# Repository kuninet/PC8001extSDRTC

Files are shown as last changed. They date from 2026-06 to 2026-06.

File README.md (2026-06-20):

# PC8001extSDRTC

PC-8001 の外部CPUバスに直結する **PICマイコン式 SDカード + RTC ドライブ** の設計資料リポジトリです。

SDアクセスを、PC-8001 のCPU外部バスに接続した **PIC18F47Q43** に肩代わりさせ、SDカードを
**Z80 の I/O デバイス**として見せます。将来は I2C RTC(DS3231等)も同じデバイスに同居させます。

ソフト側(SD-DOS)から見ると、SDアクセス下回りのドライバ(`MMC.asm`)を I/O ポート版
(`MMC_PIC.asm`)に差し替えるだけで使えます。上位のファイルシステム層は無変更です。

- ソフト本体(SD-DOS): https://github.com/kuninet/SD-DOS
- I/O プロトコル仕様(最重要): [docs/protocol.md](docs/protocol.md)
- 兄弟プロジェクト(同じ外部バス直結の流儀): [PC8001ext232C](https://github.com/kuninet/PC8001ext232C)

> ⚠️ 本リポジトリは **設計段階**です。回路・基板・PICファームはこれから物理試作します。
> まずは I/O プロトコルと、SD-DOS 側のドライバ差し替え構成を固める段階です。

## なぜ作るのか(背景)

SD-DOS の SDアクセスは 8255 PPI を使った **ビットバンギング SPI** です。これは1セクタ
(512バイト)の読み出しに実機(Z80 実効約1.84MHz)で **約0.1秒**かかり、密に音符が並ぶ
VGM再生などでは「もたつき」が出ます(Issue #68 の割り込み駆動プレイヤ検証で、ソフトの
工夫では消せないと結論)。

そこで下回りを **ハードSPI(MHz級)を持つPIC**に置き換えると、1セクタ読みが **~0.5ms** 前後、
**約200倍**高速化します。同期読みのままでももたつかなくなり、割り込み背景読みのような
小細工も不要になります。

## 設計方針(A案: 生512Bブロックデバイス)

PIC は **「512バイト単位のランダムアクセス I/O デバイス」**に徹します。

- FAT 等のファイルシステムは **Z80(SD-DOS)側**のまま。PIC は生ブロックの R/W だけを担う。
- CP/M など他のソフトからも汎用的に使える(ファイルシステム非依存)。
- PIC は周辺を全エミュレートするのではなく、**I/O 周辺デバイスに徹する**。
  クロック・主ROM・主RAM は PC-8001 が供給する(EMUZ80 とは役割が逆)。

## アーキテクチャ

```mermaid
flowchart LR
    subgraph PC["PC-8001 外部CPUバス (5V)"]
        BUS["A0-A7 / D0-D7<br/>/IORQ /RD /WR /RESET"]
        WAIT["/WAIT (PICが駆動)"]
    end

    PIC["PIC18F47Q43<br/>I/Oポートデコード (D0H-D6H)<br/>512B セクタバッファ<br/>コマンド/データ/ステータス"]
    SD["microSD"]
    RTC["RTC DS3231 (将来)"]

    BUS <-->|"A0-A7 / D0-D7 / 制御"| PIC
    PIC -->|"/WAIT ハンドシェイク"| WAIT
    PIC <-->|SPI| SD
    PIC <-.->|I2C| RTC
```

I/O ポートは PC-8001 未割り当ての拡張領域 **D0H-D6H** に割り当てます。
詳細は [docs/protocol.md](docs/protocol.md) を参照してください(SD-DOS と共有する契約)。

| ポート | R/W | 役割 |
|---|---|---|
| D0H | W | コマンド(0=READ, 1=WRITE, 2=STATUS, 3=INIT、将来RTC) |
| D1H-D4H | W | セクタアドレス 32bit(LSB→MSB) |
| D5H | R/W | データFIFO(512B セクタバッファ ストリーム入出力) |
| D6H | R | ステータス(bit0=READY, bit1=BUSY, bit7=ERROR) |

### タイミングの見積り

実効1.84MHz → 1 I/O サイクル ≒ 2.2μs。PIC を64MHzで回すと **約35命令ぶん**の猶予があり、
EMUZ80 の 1350ns/21命令より約5倍楽です。単純なレジスタ応答は /WAIT 無しでも届く見込みですが、
**/WAIT で安全マージンを取る**設計にします。遅いSD読み中(~0.5ms)はZ80を /WAIT で固めず、
ステータスを polling して待つ方式とし、N-BASIC の割り込みを止めません。

## PIC を PIC18F47Q43 にする理由

| 型番 | RAM | Flash | MaxMHz | CLC | 備考 |
|---|---|---|---|---|---|
| **PIC18F47Q43(採用)** | 8KB | 128KB | 64 | あり | 512Bバッファ後も余裕、EMUZ80 実績、SPI×2/I2C |
| PIC18F46K22 | 4KB | 64KB | 64 | なし | バッファは足りるが余裕減、デコード外付け要かも |
| PIC18F4550 以下 | ≤2KB | ≤32KB | ≤48 | なし | 512Bバッファでほぼ埋まる(非推奨) |

RAM 8KB は 512B セクタバッファ + 将来のダブルバッファ / FATキャッシュ余地に効きます。
CLC(Configurable Logic Cell)で I/O ポートデコードをハード化でき、応答に余裕が出ます。

## SD-DOS 側のビルド分け

SD-DOS は **ビットバンギング(既定)** と **PICSD** を同一ソースから作り分けます。

- `src/LABELS.asm` の `USE_PICSD EQU FALSE`(既定)を `TRUE` にすると PIC版になる。
- `src/MMC.asm`(8255ビットバンギング)/ `src/MMC_PIC.asm`(D0H-D6H I/O)を条件INCLUDEで切替。
- ビルド: 既定 `make` がビットバンギング、`make picsd` が PIC版(`build/MAIN-PICSD.cmt`)。

詳細は SD-DOS リポジトリを参照してください。

## ロードマップ

1. **/WAIT 実機検証(最優先)**: 最小PICで「D0H 読み書きエコー + /WAIT アサート/解除」だけ作り、
   PC-8001 外部バスが /WAIT を尊重するか実機確認する。
2. **PIC SDファーム**: SPI初期化 + CMD17/CMD24 でセクタ R/W、512Bバッファ、ステータス。
   ロジックアナライザで I/O プロトコルを確認する。
3. **SD-DOS `MMC_PIC.asm` 結合**: Mac側の回帰テストをフック差し替えで通し、実機で R/W。
4. **実機体感**: VGMPLAY で「もたつき消滅」を確認(本丸)。
5. **RTC フェーズ**: D0H コマンドに時計 R/W を追加、I2C DS3231 等。

## ディレクトリ構成

```
PC8001extSDRTC/
├── README.md          このファイル(設計概要)
├── Makefile           PC-8001側テスト(WAITTEST)ビルド / firmware構文チェック
├── tools/             外部ツール(tools80.jar を置く。本体は再配布しないため非コミット)
├── docs/
│   └── protocol.md    D0H-D6H I/O 仕様(SD-DOS と共有する契約。最重要)
├── hardware/
│   └── design.md      回路設計仕様・結線表・ピンアサイン・BOM
├── firmware/          PIC18F47Q43 ファーム(MPLAB X / XC8)。今は構成と関数スタブ
│   └── waittest/      /WAIT 検証用スタブ
└── test/              /WAIT ハンドシェイク検証(PC-8001側 WAITTEST.asm + 手順)
```

## ビルド

PC-8001 アセンブラ tools80.jar を `tools/` に置きます(入手方法は [tools/README.md](tools/README.md)。
ツール本体は再配布しないためリポジトリには含めません)。SD-DOS など他リポジトリには依存しません。

```sh
make            # build/WAITTEST.cmt(PC-8001側 /WAIT 検証)を生成
make fw-check   # firmware の C スタブをホストで構文チェック
```

別の場所の jar を使う場合は `make TOOLS80=/path/to/tools80.jar`。PIC ファーム本体の実機
ビルドは MPLAB X + XC8 で行います。

## 将来検討: PC-80S31(FD)互換モード

PIC+SD を PC-80S31(NEC純正フロッピーユニット)のホストインターフェースに似せれば、
無改造の N-BASIC DISK BASIC / NEC CP/M が動く可能性があります(膨大な .D88 資産が使える)。
ただし PC-80S31 は Z80+μPD765 を積んだ知的サブシステムで、互換ファームは A案の単純な
ブロックデバイスより遥かに重く、フロッピー意味論に制約されます。**当面は A案を主とし、
PIC がバス上にいる利点を活かして将来「モード」として追加し得る**設計に留めます。

## ライセンス

MIT License. [LICENSE](LICENSE) を参照してください。

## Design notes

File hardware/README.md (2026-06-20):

# hardware — 回路図・基板(設計メモ)

PC-8001 外部CPUバスに直結する PIC18F47Q43 ボードのハードウェア設計です。
回路図・基板は KiCAD で起こす予定です(本ディレクトリに追加)。

- **[design.md](design.md) … 回路設計仕様・結線表(フェーズA)。基本方針・ブロック図・
  ピンアサイン表・ネット単位の結線表・BOM。KiCAD はこの結線表をもとに引く。**

## 接続するバス信号(PC-8001 拡張バス → PIC)

- アドレス: `A0`-`A7`(I/O ポートデコード用。`D0H`-`D6H` を識別)
- データ: `D0`-`D7`(双方向。PIC が `IN` 時にドライブ)
- 制御: `/IORQ`, `/RD`, `/WR`, `/RESET`
- `/WAIT`: **PIC が駆動**(オープンコレクタ/オープンドレインで Wired-OR)

## PIC 側ペリフェラル

- microSD: ハードSPI(MSSP1)。CS/SCK/MOSI/MISO。
- (将来)RTC: I2C(MSSP2)。DS3231 等。SDA/SCL に 4.7kΩ プルアップ。
- I/O デコード: CLC(Configurable Logic Cell)で `A7..A0 == D0H..D6H` かつ `/IORQ` を
  ハード判定し、応答レイテンシを詰める。

## 検討事項(要実機検証)

- **/WAIT を PC-8001 拡張バスが尊重するか**(最優先)。尊重しない場合の回避策はソフト側で。
- データバス バッファ(74xx245 等)の向き制御を `/RD`・デコード出力で行うか、PIC直結か。
- 5V(PC-8001)と 3.3V(SD/PIC)のレベル変換。PIC18F47Q43 は 5V 動作可だが、SD は 3.3V。
- 拡張バスのバスタイミング(セットアップ/ホールド)の実測(ロジックアナライザ)。

## ポートマップ

I/O ポート割り当て(`D0H`-`D6H`)は [../docs/protocol.md](../docs/protocol.md) を参照。

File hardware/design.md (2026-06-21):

# PICSD 回路設計仕様・結線表(フェーズA)

PIC18F47Q43 を PC-8001 外部CPUバスに直結し、SDカードを D0H-D6H の I/O デバイスとして
見せるボードの設計仕様です。KiCad 入力前の「何をどう繋ぐか」を確定します。

> ✅ ピン番号・PPS 割り当て・I2C 専用 pin はデータシート(DS40002147E, Rev.E)で照合済み。
> 実機で詰める項目(/WAIT タイミング、I2C 標準レベル動作、バスバッファ要否)は §6 に分けています。

## 1. 基本方針

- **PIC は 5V 単一電源で動作させる**(PIC18F47Q43 は 5V 動作可)。
  - 理由: PC-8001 拡張バスは 5V TTL。PIC を 5V で回せば**バス側のレベル変換が一切不要**になり、
    部品点数が激減する(EMUZ80 と同じ思想)。
  - 3.3V が要るのは microSD だけ。これは **オンボードに 3.3V レギュレータ + レベル変換を持つ
    microSD モジュール**(既存 SD-DOS で使う [sdd](https://github.com/chiqlappe/sdd) 相当)を使い、
    SPI 信号は 5V ロジックのままモジュールに渡してモジュール内で整える。→ ボード上に個別の
    レベル変換ICを置かない。
  - RTC(将来)は DS3231 モジュール(5V トレラント、オンボード I2C プルアップ)を想定し、
    I2C も 5V のまま接続。
- **クロックは内部 64MHz HFINTOSC**。水晶不要(→ OSC ピンを GPIO に回せる)。
- I/O ポートデコード(`A7..A0 == D0H..D6H` かつ `/IORQ`)は **CLC でハード化**して応答を詰める。
  SPI/CLC のピンは PPS で自由に割り当て可能。

### レベル変換まとめ

| 境界 | 信号 | 方式 |
|---|---|---|
| PC-8001 ↔ PIC | A0-A7, D0-D7, /IORQ, /RD, /WR, /RESET, /WAIT | **変換なし**(両側 5V) |
| PIC ↔ microSD | SPI(SCK/MOSI/MISO/CS) | **microSDモジュールのオンボード変換**に委ねる |
| PIC ↔ RTC(将来) | I2C(SCL/SDA) | **変換なし**(DS3231 モジュールが 5V 対応) |

> 補足: 個別 microSD ソケットを使う場合は、別途 3.3V レギュレータ(AMS1117-3.3 等)+
> 4ch レベル変換(TXS0108/TXB0104 等)が必要。本仕様は**変換内蔵モジュール前提**で簡素化する。

## 2. ブロック図

```mermaid
flowchart LR
    subgraph PC["PC-8001 拡張バス (5V)"]
        BUS["A0-A7 / D0-D7<br/>/IORQ /RD /WR /RESET"]
        WAIT["/WAIT"]
    end

    subgraph BOARD["PICSD ボード (+5V 単一電源)"]
        PIC["PIC18F47Q43 @5V<br/>内部64MHz<br/>CLCで D0H-D6H デコード<br/>512B セクタバッファ"]
    end

    SD["microSD モジュール<br/>3.3Vレギュ + レベル変換 内蔵"]
    RTC["DS3231 RTC モジュール<br/>5V / I2C ・将来"]

    BUS <-->|"A0-A7 / D0-D7 / 制御"| PIC
    PIC -->|"/WAIT (OD・4.7kΩ↑ +5V)"| WAIT
    PIC <-->|"SPI: SCK / MOSI / MISO / CS"| SD
    PIC <-.->|"I2C: SCL / SDA"| RTC
```

## 3. ピンアサイン(PIC18F47Q43 / PDIP-40)

> ✅ **データシート照合済み**(DS40002147E, Rev.E)。ピン番号は Figure 2-3「40-Pin PDIP」/
> Table 3-2「40/44/48-Pin Allocation Table」の **40-Pin PDIP 列**と一致。

ポート割り当ての考え方:
- **アドレス A0-A7 は PORTC にまとめる**(1命令で読めてデコードが速い)。こうすると **PORTB が丸ごと空き**、
  ICSP の RB6/RB7 に拡張バス信号を一切載せずに済む(=書込競合を構造的に排除)。
- SPI/I2C は空いた **PORTB(RB0-RB5)** に PPS で配置。RB6/RB7 は **ICSP 専用**にする。
- データ D0-D7 は **PORTD**、制御は **PORTA**。内部発振のため OSC1/OSC2(RA7/RA6)は予備。

| pin | ポート | 割り当て | 方向 | 備考 |
|---|---|---|---|---|
| 1 | RE3/MCLR/VPP | MCLR | in | 10kΩ プルアップ + リセット回路(ICSP VPP 兼用) |
| 2 | RA0 | /IORQ | in | 拡張バス。デコード/CLC入力 |
| 3 | RA1 | /RD | in | 拡張バス。データ方向制御 |
| 4 | RA2 | /WR | in | 拡張バス。書込ストローブ |
| 5 | RA3 | /RESET | in | 拡張バス(PIC初期化トリガにも) |
| 6 | RA4 | /WAIT | out(OD) | **オープンドレイン**。4.7kΩで+5VへWired-OR |
| 7 | RA5 | (予備) | - | 拡張用 |
| 8 | RE0 | (予備) | - | |
| 9 | RE1 | (予備) | - | |
| 10 | RE2 | (予備) | - | |
| 11 | VDD | +5V | pwr | 0.1µF パスコン |
| 12 | VSS | GND | pwr | |
| 13 | RA7/OSC1 | (予備) | - | 内部発振のため空き |
| 14 | RA6/OSC2 | (予備) | - | 同上 |
| 15 | RC0 | A0 | in | アドレスバス |
| 16 | RC1 | A1 | in | |
| 17 | RC2 | A2 | in | |
| 18 | RC3 | A3 | in | 本来I2C専用pinだがアドレス入力に使用(GPIOとして問題なし) |
| 19 | RD0 | D0 | bidir | データバス |
| 20 | RD1 | D1 | bidir | |
| 21 | RD2 | D2 | bidir | |
| 22 | RD3 | D3 | bidir | |
| 23 | RC4 | A4 | in | 本来I2C専用pinだがアドレス入力に使用(GPIOとして問題なし) |
| 24 | RC5 | A5 | in | アドレスバス |
| 25 | RC6 | A6 | in | |
| 26 | RC7 | A7 | in | |
| 27 | RD4 | D4 | bidir | データバス |
| 28 | RD5 | D5 | bidir | |
| 29 | RD6 | D6 | bidir | |
| 30 | RD7 | D7 | bidir | |
| 31 | VSS | GND | pwr | |
| 32 | VDD | +5V | pwr | 0.1µF パスコン |
| 33 | RB0 | SD_SCK | out | SPI1 SCK(PPSで割当) |
| 34 | RB1 | SD_MOSI(SDO1) | out | SPI1 SDO(PPSで割当) |
| 35 | RB2 | SD_MISO(SDI1) | in | SPI1 SDI(PPSで割当) |
| 36 | RB3 | SD_CS | out | GPIO(CS手動制御)。リセット時デセレクト用にプルアップ推奨 |
| 37 | RB4 | RTC_SCL | out(OD) | I2C(PPSで割当)・標準STレベル・将来 |
| 38 | RB5 | RTC_SDA | bidir(OD) | I2C(PPSで割当)・標準STレベル・将来 |
| 39 | RB6 | ICSPCLK | - | **ICSP専用**。アプリ未使用。FWで**内部**弱プルアップ(WPUB)を有効にしフロート回避。外付け抵抗は載せない(PGC/PGD への負荷はNG) |
| 40 | RB7 | ICSPDAT | - | 同上 |

割り当ての要点:
- **A0-A7 = PORTC**(入力)。1命令で読めてデコードが速い。`D0H-D6H` 判定は A7..A3=11010、A2..A0=ポート選択。
  RC3/RC4 は本来 I2C 専用 pin だが、ここではアドレス入力として使用(通常 GPIO として問題なし)。
- **D0-D7 = PORTD**(双方向)。`IN` 時のみ TRIS を出力に切り替えてドライブ。
- **制御線 = PORTA**(RA0-RA4)。/WAIT は RA4 を ODCON でオープンドレイン。
- **SPI = RB0-RB3**(SCK/MOSI/MISO/CS)。SCK1/SDO1/SDI1 は PPS 再配置可なので RB0-RB2 へ。CS は GPIO(RB3)。
- **I2C = RB4/RB5**(将来 RTC)。PPS で割当。ただし I2C 専用ロジックレベルを持つ pin は **RC3/RC4 のみ**
  (Table 3-2 Note 4)で、それらはアドレスに使うため、I2C は**標準 TTL/ST レベル**での動作になる。
  低速・1デバイス・モジュール側プルアップ前提なら実用上問題ないが、実機で確認(§6)。
- **ICSP = RB6/RB7**(+ MCLR/VDD/VSS)。**拡張バス信号を一切載せない**配置なので、PC-8001 に挿したままでも
  抜いても**書込競合なし**(ジャンパ不要)。アプリ動作中 RB6/RB7 は ICSP ヘッダにしか繋がらないため、
  FW で**内部**弱プルアップ(WPUB)を有効にしてフロートを避ける(PGC/PGD に**外付け**プルアップは載せない)。

## 4. 結線表(ネット単位)

### 4.1 PC-8001 拡張バス ↔ PIC

| ネット | PC-8001 拡張バス | PIC(pin) | 備考 |
|---|---|---|---|
| A0 | A0 | RC0(15) | アドレスバス |
| A1 | A1 | RC1(16) | |
| A2 | A2 | RC2(17) | |
| A3 | A3 | RC3(18) | |
| A4 | A4 | RC4(23) | |
| A5 | A5 | RC5(24) | |
| A6 | A6 | RC6(25) | |
| A7 | A7 | RC7(26) | |
| D0 | D0 | RD0(19) | 双方向 |
| D1 | D1 | RD1(20) | 双方向 |
| D2 | D2 | RD2(21) | 双方向 |
| D3 | D3 | RD3(22) | 双方向 |
| D4 | D4 | RD4(27) | 双方向 |
| D5 | D5 | RD5(28) | 双方向 |
| D6 | D6 | RD6(29) | 双方向 |
| D7 | D7 | RD7(30) | 双方向 |
| /IORQ | /IORQ | RA0(2) | デコード/CLC入力 |
| /RD | /RD | RA1(3) | データ方向制御 |
| /WR | /WR | RA2(4) | 書き込みストローブ |
| /RESET | /RESET | RA3(5) | |
| /WAIT | /WAIT | RA4(6) | OD出力、4.7kΩ↑+5V |
| +5V | +5V | VDD(11,32) | |
| GND | GND | VSS(12,31) | |

> データバス保護/駆動強化のため **74LVC245 を D0-D7 に挟む案**もある(向きは /RD・デコード出力で
> 制御)。まずは PIC 直結で試作し、必要なら追加する。

### 4.2 PIC ↔ microSD モジュール

| ネット | PIC(pin) | microSDモジュール | 備考 |
|---|---|---|---|
| SD_SCK | RB0(33) | CLK/SCK | SPIクロック |
| SD_MOSI | RB1(34) | CMD/DI/MOSI | |
| SD_MISO | RB2(35) | DAT0/DO/MISO | |
| SD_CS | RB3(36) | CS/DAT3 | リセット時デセレクト用に 10kΩ↑+5V 推奨 |
| +5V | VDD | VCC | モジュール内で3.3V生成 |
| GND | VSS | GND | |

### 4.3 PIC ↔ RTC モジュール(将来)

| ネット | PIC(pin) | DS3231モジュール | 備考 |
|---|---|---|---|
| RTC_SCL | RB4(37) | SCL | I2C(PPS割当・標準STレベル)。モジュール側プルアップ有 |
| RTC_SDA | RB5(38) | SDA | I2C(PPS割当・標準STレベル) |
| +5V | VDD | VCC | |
| GND | VSS | GND | |

## 5. BOM(暫定)

| # | 部品 | 型番/値 | 数 | 備考 |
|---|---|---|---|---|
| 1 | マイコン | PIC18F47Q43-I/P(PDIP-40) | 1 | 5V動作・内部64MHz |
| 2 | microSD モジュール | 3.3Vレギュ+レベル変換内蔵タイプ | 1 | sdd 相当 |
| 3 | RTC モジュール(将来) | DS3231(電池付) | 1 | I2C・5V対応 |
| 4 | データバスバッファ(任意) | 74LVC245 | 0-1 | 直結で不足時に追加 |
| 5 | パスコン | 0.1µF セラミック | 2-3 | 各VDD近傍 |
| 6 | バルクコンデンサ | 10µF | 1 | 電源安定 |
| 7 | プルアップ(/WAIT) | 4.7kΩ | 0 | **PC-8001 母板側でプルアップ済みのためボード側は不要**(OD Wired-OR) |
| 8 | プルアップ(MCLR) | 10kΩ | 1 | Figure 4-1 R1 |
| 9 | 直列抵抗(MCLR) | 100〜470Ω | 1 | Figure 4-1 R2(ICSP保護) |
| 10 | パスコン(MCLR) | 0.1µF | 1 | Figure 4-1 C2 |
| 11 | プルアップ(I2C, 将来) | 4.7kΩ ×2 | 0-2 | モジュールに有れば不要 |
| 12 | プルアップ(SD_CS, 任意) | 10kΩ | 0-1 | 起動直後の SD 誤選択防止 |
| 13 | ICソケット | 40pin DIP | 1 | |
| 14 | 拡張バスコネクタ | PC-8001 拡張バス対応 | 1 | 232C/sdd 流用 |
| 15 | ICSPヘッダ | 5pin(MCLR/VDD/VSS/RB6/RB7) | 1 | PICKit等で書込。RB6/RB7はアプリ未使用なのでバス競合なし |
| 16 | ピンヘッダ | モジュール接続用 | 適量 | |

## 6. データシート照合の結果と残課題

### 照合済み(DS40002147E)
- ✅ **PDIP-40 ピン番号**: Figure 2-3 / Table 3-2 の 40-Pin PDIP 列と本表が一致。
- ✅ **SPI の PPS 割当**: SCK1/SDO1/SDI1 は PPS 再配置可能(Table 3-2 Note 1/2)。RB0-RB2 を選択。
- ✅ **I2C 専用レベル pin**: 本パートで I2C 専用ロジックレベルを持つのは **RC3/RC4 のみ**(Table 3-2 Note 4)。
  他ピンも PPS で SCL/SDA を割り当て可能だが、入力レベルは I2C/SMBus 専用しきい値ではなく
  **標準 TTL/ST**(INLVL で選択)になる、とデータシート本文で確認。本設計は RC3/RC4 をアドレスに
  使うため、I2C(RB4/RB5)は標準 ST レベル動作。
- ✅ **電源/MCLR**: VDD=11,32 / VSS=12,31 / MCLR=1。Figure 4-1 の推奨(10kΩ↑+100〜470Ω直列+0.1µF)。
- ✅ **ICSP 競合の構造排除**: RB6/RB7 に拡張バス信号を載せない配置とし、書込時のバス競合を回避。

### 実機で詰める(フェーズB)
1. **/WAIT のタイミング**(最優先): 1サイクル ~2.2μs 内に OD アサート/解除が間に合うか(ロジアナ実測)。
   → 最小プログラム `../test/WAITTEST.asm` + `../firmware/waittest/` で先に検証。
2. **データバス直結 vs 74LVC245**: PIC の駆動能力・バス容量で判断。まず直結で試作。
3. **I2C 標準レベル動作の確認**(RTC フェーズ): DS3231 を 5V・モジュールプルアップで接続し、
   標準 ST しきい値で安定通信するか。不安定なら専用レベル pin を使う別配置やバスバッファを再検討。
4. **SD_CS のリセット時デセレクト**: 起動直後 RB3 が入力(Hi-Z)の間に SD が誤選択されないか。
   必要なら CS プルアップ(BOM #12)で抑える。
5. **拡張バスの /WAIT ピン**: /WAIT は **PC-8001 母板側でプルアップ済み**(確認済み)なのでボード側プルアップは不要。
   OD で Low/解放のタイミングが効くかを実機で確認(項目1と一緒に)。

## 7. 関連

- I/O プロトコル(D0H-D6H): [../docs/protocol.md](../docs/protocol.md)
- /WAIT 検証: [../test/](../test/)
- データシート: PIC18F27/47/57Q43(Microchip DS40002147E)
- ハードウェア親Issue: #4 / PICSD: #1
- 同じ外部バス直結ボードの先例: [PC8001ext232C](https://github.com/kuninet/PC8001ext232C)

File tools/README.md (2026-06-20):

# tools/

ビルドに使う外部ツールを置くディレクトリ。ツール本体は再配布しないため、リポジトリには
含めない(この README 以外は `.gitignore` 対象)。

## tools80.jar

PC-8001 用アセンブラ(j80 付属)。

* 入手元: OUT of STANDARD http://upd780c1.g1.xrea.com/pc-8001/index.html の `bin/tools80_r6_50.lzh`
* `.lzh` を展開し、`tools80.jar` をこのディレクトリ(`tools/tools80.jar`)に置く
* r6_50(Ver 6.6.68)で動作確認済み。r6_44 以前は `SET` で始まるラベルがエラーになるため使わないこと
* Java 実行環境が必要。macOS では Homebrew の `openjdk` で動作確認済み

置いたら、リポジトリ直下で `make` するとビルドできる:

```sh
make            # build/WAITTEST.cmt を生成
```

別の場所の jar を使う場合は `make TOOLS80=/path/to/tools80.jar`。

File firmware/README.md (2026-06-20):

# firmware — PIC18F47Q43 ファーム(設計メモ)

MPLAB X + XC8 を想定。現状は構成と関数スタブのみ(`picsd_main.c`)。

## 役割

PC-8001 からの I/O アクセス(`D0H`-`D6H`)を受け、SD カードの生512Bブロック R/W を行う。
プロトコルは [../docs/protocol.md](../docs/protocol.md) が真実。

## 構成(予定)

```
firmware/
├── README.md
└── picsd_main.c     I/Oプロトコル処理 + SD SPI(生ブロックR/W) + /WAIT ハンドシェイク のスタブ
```

将来 `sd_spi.c` / `rtc_i2c.c` / `bus_io.c` に分割する。

## 主な処理ブロック

1. **バス I/O 受付**: CLC + 割り込み(または /IORQ ポーリング)で `IN`/`OUT` を捕捉。
   - `OUT D0H`: コマンドラッチ → 状態機械を起動。
   - `OUT D1H-D4H`: アドレスレジスタへ格納。
   - `OUT D5H`: 書き込みバッファへ蓄積(512で WRITE 実行)。
   - `IN  D5H`: 読み出しバッファから1バイト返す(ポインタ前進)。
   - `IN  D6H`: ステータスを返す。
2. **SD SPI**: 初期化(CMD0/CMD8/ACMD41)、CMD17(READ_SINGLE)、CMD24(WRITE_SINGLE)。
3. **/WAIT 制御**: 1バイト整流の数百 ns のみアサート。SDアクセス中は固めない(ステータス polling)。

## ステータスビット

`READY=bit0` / `BUSY=bit1` / `ERROR=bit7`。詳細は protocol.md。

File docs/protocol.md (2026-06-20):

# PC8001extSDRTC I/O プロトコル仕様(D0H-D6H)

PC-8001(Z80)と PIC18F47Q43 の間の **I/O ポート契約**です。SD-DOS の `src/MMC_PIC.asm` と
PIC ファームは、この仕様を共有の真実として実装します。

- 対象 I/O アドレス: **D0H-D6H**(PC-8001 未割り当ての拡張領域)
- アクセス: Z80 の `IN`/`OUT` 命令(8bit ポート I/O)
- 本仕様の版: **v0(暫定)** — 実機検証前。変更し得る。

## ポートマップ

| ポート | R/W | 名称 | 役割 |
|---|---|---|---|
| `D0H` | W | COMMAND | コマンド発行 |
| `D1H` | W | ADDR0 | セクタアドレス byte0(LSB) |
| `D2H` | W | ADDR1 | セクタアドレス byte1 |
| `D3H` | W | ADDR2 | セクタアドレス byte2 |
| `D4H` | W | ADDR3 | セクタアドレス byte3(MSB) |
| `D5H` | R/W | DATA | 512B セクタバッファのストリーム入出力(FIFO) |
| `D6H` | R | STATUS | ステータスレジスタ |

## コマンド(`D0H` に書く)

| 値 | 名称 | 動作 |
|---|---|---|
| `00H` | READ_SECTOR | ADDR のセクタを SD から PIC の512Bバッファへ読み込む。完了で `READY=1`。DATA 読み出しポインタを 0 に戻す。 |
| `01H` | WRITE_SECTOR | DATA へ512B受け取る準備をする。512バイト受領後、ADDR のセクタへ SD に書き戻す。フラッシュ完了で `READY=1`。 |
| `02H` | GET_STATUS | ステータスを更新する(明示フェッチ。副作用なし)。 |
| `03H` | INIT | SD カードを初期化/マウントする(SPIモード初期化、CMD0/CMD8/ACMD41 等)。成功で `READY=1`、失敗で `ERROR=1`。 |
| `10H`〜 | (将来)RTC | I2C RTC の読み書き(時計取得/設定)。本版では未定義。 |

## ステータスレジスタ(`D6H` を読む)

| bit | 名称 | 意味 |
|---|---|---|
| 0 | READY | 1 = 直前の操作が完了し、データ転送可 |
| 1 | BUSY | 1 = SD アクセス中 |
| 7 | ERROR | 1 = エラー発生(カード無し/CRC/タイムアウト等) |

その他のビットは予約(0 を返すこと)。

## アドレスのセマンティクス

ADDR0-3 は 32bit のアドレスで、**既存のビットバンギングドライバの `MMCADR0-3` と同一の値**です。
これは元の SDSC フロー(CMD17/CMD24)で使っていた **バイトアドレス**で、1セクタ=512バイト、
セクタを1つ進めるときは +200H(=512)します。

PIC 側はこの ADDR を同じ意味(バイトアドレス)で受け取り、SDHC のブロックアドレッシングを
使う場合は内部で 512 で割ってブロック番号に変換します。これにより SD-DOS の FS 層を無変更に
保てます。

## 転送シーケンス

### セクタ READ

```
1. OUT (D1H),ADDR0 ; … OUT (D4H),ADDR3   ; アドレスをセット
2. OUT (D0H),00H                          ; READ_SECTOR
3. wait until (IN (D6H) AND 01H) != 0     ; READY を polling(SDアクセス完了待ち)
4. 512回: IN (D5H) -> メモリ              ; DATA から1バイトずつ取り出す(PICが内部ポインタを自動前進)
```

### セクタ WRITE

```
1. OUT (D1H),ADDR0 ; … OUT (D4H),ADDR3   ; アドレスをセット
2. OUT (D0H),01H                          ; WRITE_SECTOR
3. 512回: メモリ -> OUT (D5H)             ; DATA へ1バイトずつ送る(PICが内部バッファに蓄積)
4. wait until (IN (D6H) AND 01H) != 0     ; READY を polling(フラッシュ完了待ち)
```

### 初期化(マウント)

```
1. OUT (D0H),03H                          ; INIT
2. wait until (IN (D6H) AND 01H) != 0     ; READY を polling
3. if (IN (D6H) AND 80H) != 0 -> エラー   ; ERROR ならカード無し等
```

## /WAIT ハンドシェイク

- PIC は **1バイトの DATA(`D5H`)転送とコマンド ラッチの数百 ns** の間だけ /WAIT をアサートして
  Z80 を整流する。
- **遅いSDアクセス(~0.5ms)の間は Z80 を /WAIT で固めない。** その間は STATUS を polling して待つ。
  これにより N-BASIC の周期割り込みを止めずに済む。
- 実機検証の最優先項目は「PC-8001 外部バスが /WAIT を物理的に尊重するか」。万一不可なら、
  Z80 側のアクセスを遅くする(NOP挿入)か、ステータス polling 前提のタイミングで回避する。

## SD-DOS 側エントリとの対応(参考)

`src/MMC_PIC.asm` がこのプロトコルを実装し、ビットバンギング版 `MMC.asm` と同名のエントリを
提供する(上位の FS.asm / STRM.asm は無変更)。

| SD-DOS エントリ | このプロトコルでの実装 |
|---|---|
| `MMC_INIT` | `OUT (D0H),03H` → READY 待ち → ERROR チェック |
| `MMC_BRD_CMD` | ADDR セット → `OUT (D0H),00H` → READY 待ち |
| `MMC_1RD` | `IN (D5H)` → C |
| `MMC_1WR` | `OUT (D5H),C` |
| `MMC_BRD_END` | 何もしない(PIC が CRC 処理済み) |
| `MMC_READ` | `MMC_BRD_CMD` → 512B `IN (D5H)` → アドレス +200H をブロック数ぶん |
| `MMC_WRITE` | ADDR セット → `OUT (D0H),01H` → 512B `OUT (D5H)` → READY 待ち |
| `MMC_INC_ADR` / `MMC_CLR_ADR` | `MMCADR0-3` の加算/クリア(ビットバンギング版と同一) |

## バージョン履歴

- v0(暫定): 初版。実機検証前の机上仕様。

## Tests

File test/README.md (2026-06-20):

# test — /WAIT ハンドシェイク検証

PICSD ボードの最初の関門「**PC-8001 拡張バスが /WAIT を尊重するか**」を、SD/RTC 抜きの
最小構成で確かめるための一対のプログラムです(Issue #1 の最優先タスク)。

| ファイル | 側 | 役割 |
|---|---|---|
| [`WAITTEST.asm`](WAITTEST.asm) | PC-8001(Z80) | テストポートを `IN`/`OUT` し、結果を表示 |
| [`../firmware/waittest/waittest.c`](../firmware/waittest/waittest.c) | PIC18F47Q43 | わざと遅れて応答し、その間 /WAIT を下げるスタブ |

## 仕組み

PIC を**意図的に遅く**します(/WAIT を Low → 数µs 待つ → データを出す → /WAIT 解放)。

```mermaid
sequenceDiagram
    participant Z as PC-8001 (Z80)
    participant P as PIC (テストデバイス)
    Z->>P: IN A,(D0H) 開始 (/IORQ + /RD)
    P-->>Z: /WAIT を Low(まだデータを出さない)
    Note over Z: ウェイトステート挿入で待機<br/>← ここが「効くか」の本丸
    P->>Z: D0-D7 に last(=55H)を出す
    P-->>Z: /WAIT 解放
    Note over Z: データをラッチしてサイクル終了
```

- **/WAIT が効いていれば**: Z80 は待ってから読むので、読み値は常に正しい(`55H`)。
- **/WAIT が効いていなければ**: Z80 が待たずに読むので、ゴミ値になる。

## 契約(両者で一致させる値)

- テストポート = **D0H**(WAITTEST は 9003H POKE で変更可)
- PIC 内部レジスタ `last`(電源投入時 = **55H**)
- READ → `last` を返す / WRITE → `last` に格納(どちらも /WAIT で整流)

## ビルドと実行

### PC-8001 側(WAITTEST.asm)
tools80(j80 付属)でアセンブルします。`tools/tools80.jar` を置けば(入手方法は
[../tools/README.md](../tools/README.md))、リポジトリ直下で:

```sh
make                     # build/WAITTEST.cmt を生成
# 別パスの tools80 を使う場合:
make TOOLS80=/path/to/tools80.jar
```

手で叩く場合:

```sh
printf 'OK\n' | java -jar tools/tools80.jar -tgt=z80 test/WAITTEST.asm
```

`.asm` は Shift-JIS です。生成した `WAITTEST.cmt` を実機へ LOAD し、モニタで **G9000** で起動します。

### PIC 側(waittest.c)
MPLAB X + XC8。`firmware/waittest/waittest.c` のスタブ関数(バス信号の捕捉・/WAIT 駆動・
データバス方向)を実機ピンに合わせて実装します。ピン割り当ては
[`../hardware/design.md`](../hardware/design.md) を参照。

## 結果の読み方

画面表示: `RD=xx NG=nnn WR=yy`

| 表示 | 意味 | 成功 |
|---|---|---|
| `RD` | テストポートの最初の読み値 | `55` |
| `NG` | 256回読んで `55H` と一致しなかった回数 | `000` |
| `WR` | `A5H` を書いて読み戻した値(write→read エコー) | `A5` |

- **`RD=55 NG=000 WR=A5`** → /WAIT が効き、双方向の I/O が成立。**合格**。
- `NG` が多い / `RD` がゴミ → /WAIT が効いていない、または遅延が足りない。
  - まず `waittest.c` の `WAIT_DELAY_LOOPS` を増減して挙動を見る。
  - それでも直らなければ /WAIT 配線(拡張バスの /WAIT ピン → Z80 /WAIT、プルアップ/Wired-OR)を疑う。
  - 決定的な確認はロジックアナライザで /WAIT・/IORQ・/RD・CLK を観測し、サイクルが伸びているか見る。

## 関連

- ピンアサイン・結線: [../hardware/design.md](../hardware/design.md)
- I/O プロトコル: [../docs/protocol.md](../docs/protocol.md)
- Issue: PICSD #1 / ハード #4

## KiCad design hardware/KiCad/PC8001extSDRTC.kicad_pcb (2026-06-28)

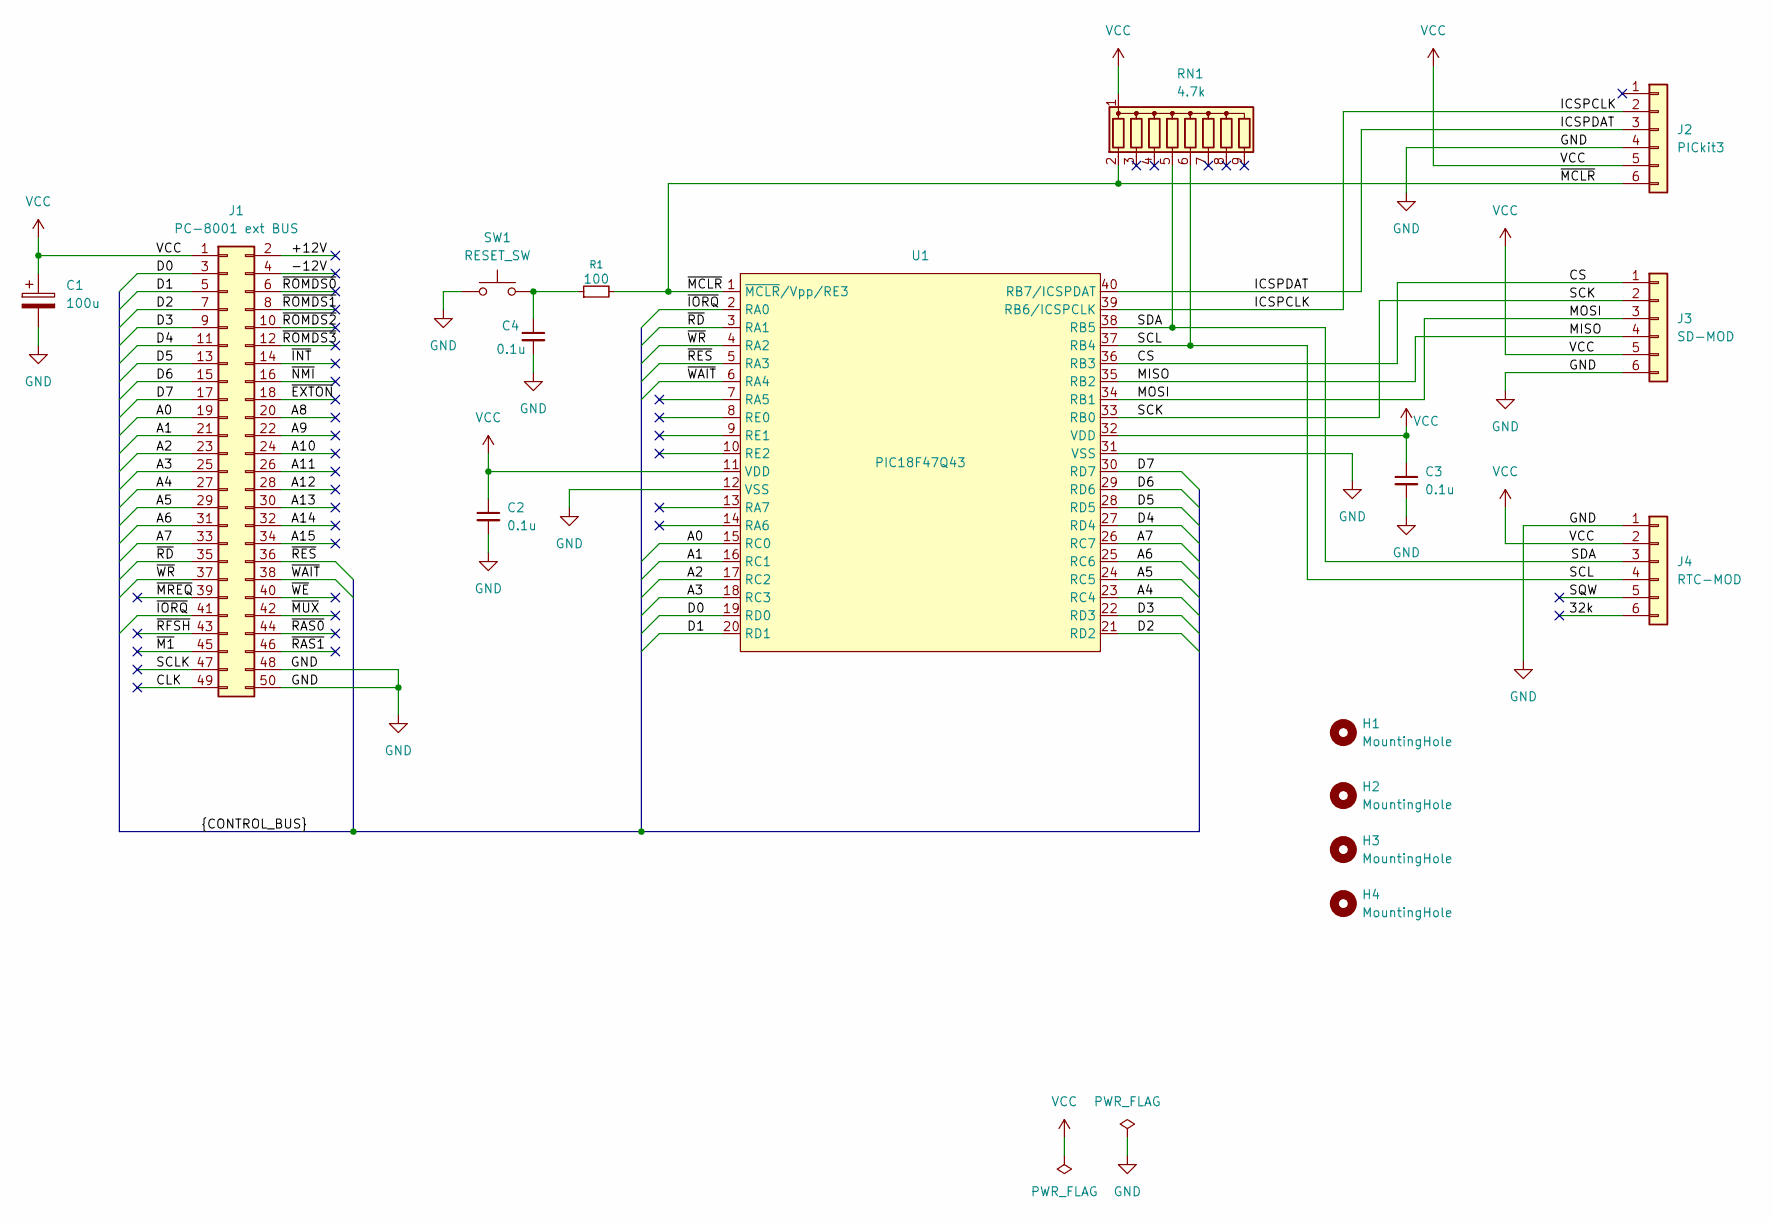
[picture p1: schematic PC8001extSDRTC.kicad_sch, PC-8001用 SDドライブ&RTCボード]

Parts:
C1: 100u; CP_Radial_D6.3mm_P2.50mm
C2, C3, C4: 0.1u; C_Disc_D3.0mm_W1.6mm_P2.50mm
H1, H2, H3, H4: MountingHole; MountingHole_3.2mm_M3
J1: PC-8001 ext BUS; PinHeader_2x25_P2.54mm_Horizontal
J2: PICkit3; PinHeader_1x06_P2.54mm_Horizontal
J3: SD-MOD; PinHeader_1x06_P2.54mm_Horizontal
J4: RTC-MOD; PinHeader_1x06_P2.54mm_Horizontal
R1: 100; R_Axial_DIN0207_L6.3mm_D2.5mm_P10.16mm_Horizontal
RN1: 4.7k; R_Array_SIP9
SW1: RESET_SW; SW_PUSH_6mm_H4.3mm
U1: PIC18F47Q43; DIP-40_W15.24mm_Socket

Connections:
/32k: J4.6
/+12V: J1.2
/-12V: J1.4
/A0: J1.19, U1.15 (RC0)
/A1: J1.21, U1.16 (RC1)
/A2: J1.23, U1.17 (RC2)
/A3: J1.25, U1.18 (RC3)
/A4: J1.27, U1.23 (RC4)
/A5: J1.29, U1.24 (RC5)
/A6: J1.31, U1.25 (RC6)
/A7: J1.33, U1.26 (RC7)
/A8: J1.20
/A9: J1.22
/A10: J1.24
/A11: J1.26
/A12: J1.28
/A13: J1.30
/A14: J1.32
/A15: J1.34
/CLK: J1.49
/CS: J3.1, U1.36 (RB3)
/D0: J1.3, U1.19 (RD0)
/D1: J1.5, U1.20 (RD1)
/D2: J1.7, U1.21 (RD2)
/D3: J1.9, U1.22 (RD3)
/D4: J1.11, U1.27 (RD4)
/D5: J1.13, U1.28 (RD5)
/D6: J1.15, U1.29 (RD6)
/D7: J1.17, U1.30 (RD7)
/ICSPCLK: J2.2, U1.39 (RB6/ICSPCLK)
/ICSPDAT: J2.3, U1.40 (RB7/ICSPDAT)
/MISO: J3.4, U1.35 (RB2)
/MOSI: J3.3, U1.34 (RB1)
/SCK: J3.2, U1.33 (RB0)
/SCL: J4.4, RN1.6 (R5), U1.37 (RB4)
/SCLK: J1.47
/SDA: J4.3, RN1.5 (R4), U1.38 (RB5)
/SQW: J4.5
/~EXTON: J1.18
/~INT: J1.14
/~IORQ: J1.41, U1.2 (RA0)
/~M1: J1.45
/~MCLR: J2.6, R1.2, RN1.2 (R1), U1.1 (~MCLR/Vpp/RE3)
/~MREQ: J1.39
/~MUX: J1.42
/~NMI: J1.16
/~RAS0: J1.44
/~RAS1: J1.46
/~RD: J1.35, U1.3 (RA1)
/~RES: J1.36, U1.5 (RA3)
/~RFSH: J1.43
/~ROMDS0: J1.6
/~ROMDS1: J1.8
/~ROMDS2: J1.10
/~ROMDS3: J1.12
/~WAIT: J1.38, U1.6 (RA4)
/~WE: J1.40
/~WR: J1.37, U1.4 (RA2)
GND: C1.2, C2.2, C3.2, C4.2, J1.48, J1.50, J2.4, J3.6, J4.1, SW1.1, U1.12 (VSS), U1.31 (VSS)
unnamed: C4.1, R1.1, SW1.2
VCC: C1.1, C2.1, C3.1, J1.1, J2.5, J3.5, J4.2, RN1.1 (common), U1.11 (VDD), U1.32 (VDD)

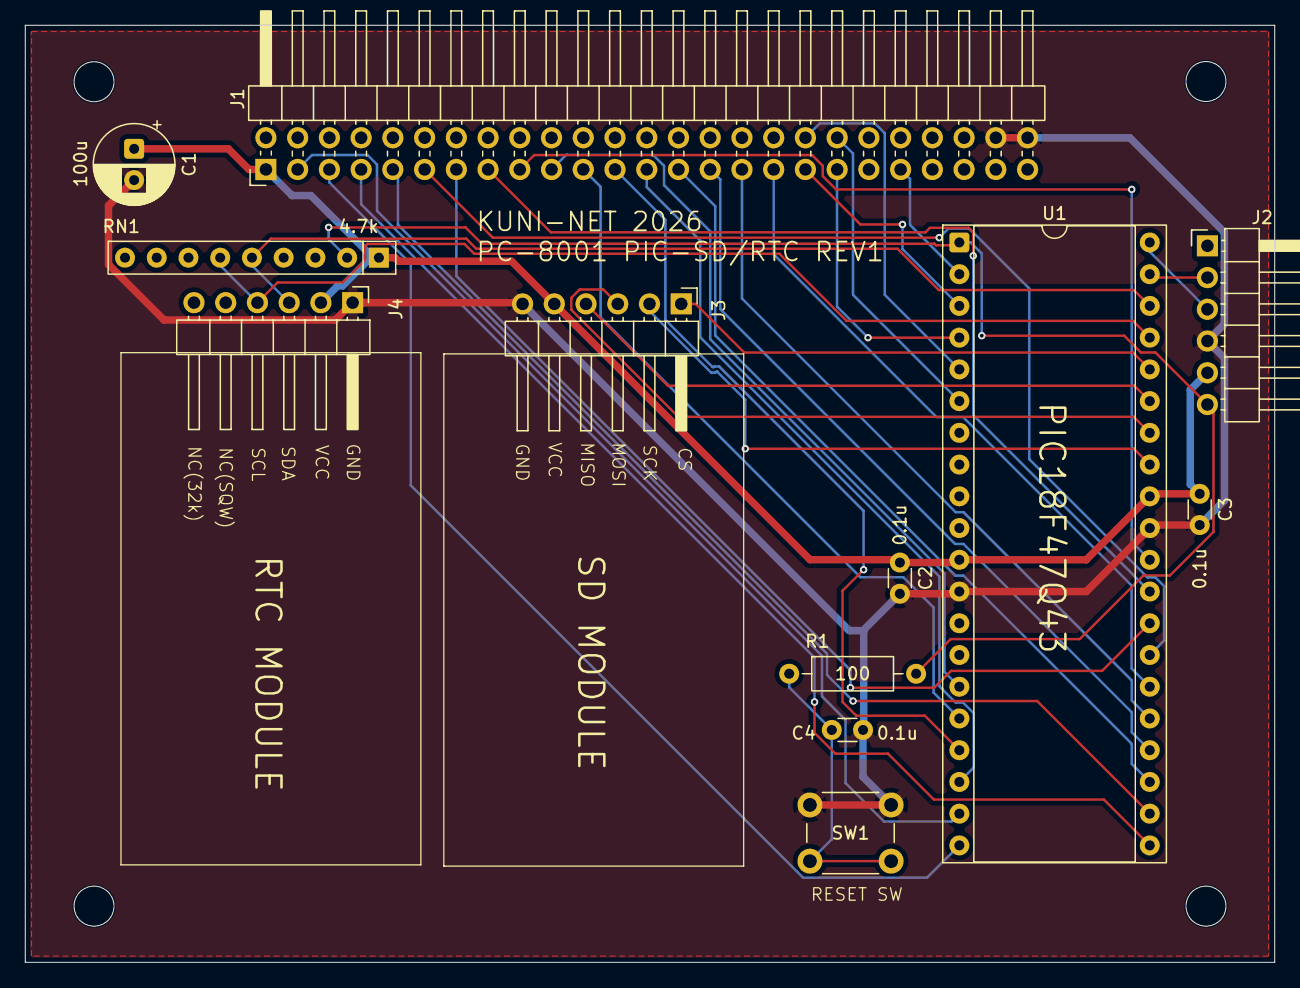
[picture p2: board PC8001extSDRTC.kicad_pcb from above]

Board: 2 copper layers, 100.0 x 75.0 mm, 16 parts (0 on the bottom side), 33 nets.

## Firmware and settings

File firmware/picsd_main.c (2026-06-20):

/*
 * picsd_main.c - PC8001extSDRTC PIC18F47Q43 ファーム(スタブ)
 *
 * PC-8001 外部CPUバス直結。SDカードを Z80 の I/O デバイス(D0H-D6H)として見せる。
 * I/O プロトコルの真実は ../docs/protocol.md を参照。
 *
 * 本ファイルは設計段階の骨格です。実機ファームではバスI/O捕捉(CLC/割り込み)、
 * SD SPI、/WAIT 制御を実装します。
 */

#include <stdint.h>

/* ---- I/O ポート(Z80 side, D0H-D6H) ---- */
#define PORT_CMD    0xD0u   /* W  コマンド            */
#define PORT_ADR0   0xD1u   /* W  アドレス byte0(LSB)*/
#define PORT_ADR1   0xD2u   /* W  アドレス byte1      */
#define PORT_ADR2   0xD3u   /* W  アドレス byte2      */
#define PORT_ADR3   0xD4u   /* W  アドレス byte3(MSB)*/
#define PORT_DATA   0xD5u   /* R/W 512B データFIFO    */
#define PORT_STAT   0xD6u   /* R  ステータス          */

/* ---- コマンド ---- */
#define CMD_READ    0x00u
#define CMD_WRITE   0x01u
#define CMD_STATUS  0x02u
#define CMD_INIT    0x03u

/* ---- ステータスビット ---- */
#define ST_READY    0x01u
#define ST_BUSY     0x02u
#define ST_ERROR    0x80u

/* ---- 状態 ---- */
static uint8_t  sd_buf[512];   /* セクタバッファ            */
static uint16_t buf_ptr;       /* DATA ストリーム位置       */
static uint32_t sd_addr;       /* バイトアドレス(MMCADR相当)*/
static volatile uint8_t status;

/* ---- SD SPI(スタブ。実装は sd_spi.c へ分割予定) ---- */
static int  sd_init(void);                       /* CMD0/CMD8/ACMD41        */
static int  sd_read_block(uint32_t addr, uint8_t *dst);   /* CMD17           */
static int  sd_write_block(uint32_t addr, const uint8_t *src); /* CMD24      */

/* ---- コマンドディスパッチ ---- */
static void do_command(uint8_t cmd)
{
    switch (cmd) {
    case CMD_INIT:
        status = ST_BUSY;
        status = sd_init() == 0 ? ST_READY : (ST_READY | ST_ERROR);
        break;
    case CMD_READ:
        status = ST_BUSY;
        if (sd_read_block(sd_addr, sd_buf) == 0) {
            buf_ptr = 0;
            status = ST_READY;
        } else {
            status = ST_READY | ST_ERROR;
        }
        break;
    case CMD_WRITE:
        /* DATA へ512B受領後に sd_write_block() を呼ぶ。ここでは受領開始だけ。 */
        status = ST_BUSY;
        buf_ptr = 0;
        break;
    case CMD_STATUS:
    default:
        break;
    }
}

/* ---- バス I/O ハンドラ(スタブ) ----
 * 実機では /IORQ 立ち下がりを CLC/割り込みで捕捉し、A0-A7 と /RD,/WR で分岐する。
 * 必要な数百 ns だけ /WAIT をアサートして整流する(SDアクセス中は固めない)。
 */
void on_io_write(uint8_t port, uint8_t value)
{
    switch (port) {
    case PORT_CMD:  do_command(value); break;
    case PORT_ADR0: sd_addr = (sd_addr & 0xFFFFFF00u) | value; break;
    case PORT_ADR1: sd_addr = (sd_addr & 0xFFFF00FFu) | ((uint32_t)value << 8); break;
    case PORT_ADR2: sd_addr = (sd_addr & 0xFF00FFFFu) | ((uint32_t)value << 16); break;
    case PORT_ADR3: sd_addr = (sd_addr & 0x00FFFFFFu) | ((uint32_t)value << 24); break;
    case PORT_DATA:
        sd_buf[buf_ptr++] = value;
        if (buf_ptr >= 512u) {
            status = ST_BUSY;
            status = sd_write_block(sd_addr, sd_buf) == 0
                         ? ST_READY : (ST_READY | ST_ERROR);
        }
        break;
    default: break;
    }
}

uint8_t on_io_read(uint8_t port)
{
    switch (port) {
    case PORT_DATA:
        return (buf_ptr < 512u) ? sd_buf[buf_ptr++] : 0xFFu;
    case PORT_STAT:
        return status;
    default:
        return 0xFFu;
    }
}

/* ---- SD SPI スタブ実装(TODO) ---- */
static int sd_init(void)                                  { return 0; }
static int sd_read_block(uint32_t addr, uint8_t *dst)     { (void)addr; (void)dst; return 0; }
static int sd_write_block(uint32_t addr, const uint8_t *src){ (void)addr; (void)src; return 0; }

void main(void)
{
    status = 0;
    buf_ptr = 0;
    sd_addr = 0;
    /* TODO: クロック/CLC/SPI/I2C 初期化、バス I/O 割り込み許可 */
    for (;;) {
        /* バス I/O は割り込み駆動。本ループはアイドル/RTC ポーリング等。 */
    }
}

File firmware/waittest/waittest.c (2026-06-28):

/*
 * waittest.c - /WAIT ハンドシェイク検証用 PIC18F47Q43 ファーム
 *
 * 目的: PC-8001 拡張バスが /WAIT を尊重するか(PICが /WAIT を下げると Z80 が
 *       マシンサイクルを伸ばして待つか)を最小構成で確かめる。SD/RTC は不要。
 *
 * PC-8001側テスト: ../../test/WAITTEST.asm(LOAD → G9000)
 *
 * 契約(WAITTEST.asm と対):
 *   - テストポート = TEST_PORT(既定 D0H)。
 *   - 内部レジスタ last(電源投入時 = 0x55)。
 *   - READ(IN)  : /WAIT を Low → 意図的に遅延 → データバスに last を出す → /WAIT 解放。
 *   - WRITE(OUT): /WAIT を Low → 少し待って D0-D7 を取り込み last へ → /WAIT 解放。
 *
 * 判定の考え方:
 *   /WAIT が効いていれば、PIC をわざと遅くしても Z80 は待ってから読むので
 *   読み値は常に正しい(0x55)。効いていなければゴミ値になる。
 *
 * ピン割り当て(../../hardware/design.md と一致):
 *   /IORQ = RA0(in) / /RD = RA1(in) / /WR = RA2(in) / /RESET = RA3(in)
 *   /WAIT = RA4(out, オープンドレイン) … 母板側プルアップで Wired-OR
 *   A0-A7 = RC0-RC7(in, PORTC) / D0-D7 = RD0-RD7(bidir, PORTD)
 *   クロック = 内部 64MHz HFINTOSC(水晶不要)
 *
 * 方式: 割り込みではなく単純ポーリング(最小テストのため)。/IORQ がアサート
 *   されたら自テストポート宛か即デコードし、自分宛なら /WAIT を下げて整流する。
 *   他ポート宛は一切 /WAIT を触らない(機械全体を止めないため)。
 *
 * ビルド: MPLAB X + XC8(PIC18F47Q43)。本ファイルはホストの構文チェック
 *   (`make fw-check`)も通るよう、PIC固有部を __XC8 でガードしている。
 */

#include <stdint.h>

#ifdef __XC8
#include <xc.h>

/* ===== コンフィグレーションビット(PIC18F47Q43) ===== */
// CONFIG1
#pragma config FEXTOSC = OFF         /* 外部発振子は未使用            */
#pragma config RSTOSC = HFINTOSC_64MHZ /* リセット直後から内部64MHz   */
// CONFIG2
#pragma config CLKOUTEN = OFF
#pragma config PR1WAY = ON
#pragma config CSWEN = ON
#pragma config FCMEN = ON
// CONFIG3
#pragma config MCLRE = EXTMCLR       /* MCLR リセット回路を使う        */
#pragma config PWRTS = PWRT_OFF
#pragma config MVECEN = OFF
#pragma config IVT1WAY = ON
#pragma config LPBOREN = OFF
#pragma config BOREN = SBORDIS
// CONFIG4
#pragma config BORV = VBOR_1P9
#pragma config ZCD = OFF
#pragma config PPS1WAY = OFF
#pragma config STVREN = ON
#pragma config LVP = ON
#pragma config XINST = OFF
// CONFIG5
#pragma config WDTCPS = WDTCPS_31
#pragma config WDTE = OFF             /* ウォッチドッグ無効            */
// CONFIG6
#pragma config WDTCWS = WDTCWS_7
#pragma config WDTCCS = SC
// CONFIG7
#pragma config BBSIZE = BBSIZE_512
#pragma config BBEN = OFF
#pragma config SAFEN = OFF
#pragma config DEBUG = OFF
// CONFIG8
#pragma config WRTB = OFF
#pragma config WRTC = OFF
#pragma config WRTD = OFF
#pragma config WRTSAF = OFF
#pragma config WRTAPP = OFF
// CONFIG9
#pragma config CP = OFF

#define _XTAL_FREQ 64000000UL
#endif /* __XC8 */

#define TEST_PORT   0xD0u
#define INIT_LAST   0x55u

/* 意図的な遅延量(/WAIT を下げている時間)。
 * まず大きめ(数µs相当)にして「遅くても正しく読めるか」を見る。
 * /WAIT が効くと確認できたら徐々に詰める。 */
#define WAIT_DELAY_LOOPS  200u

static volatile uint8_t last = INIT_LAST;

/* ---- ハード抽象 ---- */
static void     hw_init(void);           /* クロック/ポート/ODCON 初期化     */
static uint8_t  bus_iorq_active(void);   /* /IORQ アサート中か               */
static uint8_t  bus_addr(void);          /* A0-A7 を読む                    */
static uint8_t  bus_rd_active(void);     /* /RD アサート中か                */
static uint8_t  bus_wr_active(void);     /* /WR アサート中か                */
static uint8_t  bus_read_data(void);     /* D0-D7 を読む(WRITE時)         */
static void     bus_drive_data(uint8_t); /* D0-D7 を出力(READ時)          */
static void     bus_release_data(void);  /* D0-D7 をハイインピーダンスへ    */
static void     wait_assert(void);       /* /WAIT を Low(オープンドレイン)*/
static void     wait_release(void);      /* /WAIT を解放                    */

static void spin(uint16_t n)
{
    while (n--) {
#ifdef __XC8
        NOP();
#endif
    }
}

/* テストポートへのアクセス1回を処理する。
 * /IORQ がアサートされてから自ポート宛かを判定し、自分宛のときだけ /WAIT を使う。 */
static void handle_io(void)
{
    if (!bus_iorq_active()) {
        return;                 /* I/O サイクルでない */
    }
    if (bus_addr() != TEST_PORT) {
        return;                 /* 自テストポート以外は無視(/WAIT も触らない) */
    }

    if (bus_rd_active()) {
        /* READ: 先に /WAIT を下げ、わざと遅れてからデータを出す */
        wait_assert();
        spin(WAIT_DELAY_LOOPS);
        bus_drive_data(last);
        wait_release();
        /* Z80 がラッチし切る(/RD 解放)までデータを保持してから解放する */
        while (bus_rd_active()) { }
        bus_release_data();
    } else if (bus_wr_active()) {
        /* WRITE: /WAIT で整流してから取り込む */
        wait_assert();
        spin(WAIT_DELAY_LOOPS);
        last = bus_read_data();
        wait_release();
    }

    /* サイクル完了(/IORQ 解放)まで待ち、同一アクセスの二重処理を防ぐ */
    while (bus_iorq_active()) { }
}

void main(void)
{
    last = INIT_LAST;
    hw_init();
    for (;;) {
        handle_io();
    }
}

/* ===== ハード実装 ===== */
#ifdef __XC8

/*
 * RA0=/IORQ RA1=/RD RA2=/WR RA3=/RESET RA4=/WAIT(OD)
 * RC0-7=A0-A7  RD0-7=D0-D7
 * 制御線・アドレスはアクティブ Low(アサート=0)。
 */
static void hw_init(void)
{
    /* 内部 64MHz を明示設定(RSTOSC で既定だが念のため) */
    OSCFRQ = 0x08;              /* HFFRQ = 64 MHz */
    OSCCON1 = 0x00;             /* NDIV=1(分周なし) */

    /* 全ピン デジタル(アナログ機能オフ) */
    ANSELA = 0x00;
    ANSELC = 0x00;
    ANSELD = 0x00;
    ANSELB = 0x00;
    ANSELE = 0x00;

    /* PORTA: RA0-RA3 入力(制御線)、RA4 出力(/WAIT) */
    TRISA = 0xEF;              /* 1110_1111: RA4 のみ出力 */
    ODCONA = 0x10;            /* RA4 をオープンドレインに */
    LATAbits.LATA4 = 1;       /* /WAIT 解放(Hi-Z=母板プルアップで High) */

    /* PORTC: A0-A7 入力 */
    TRISC = 0xFF;

    /* PORTD: D0-D7 既定は入力(Hi-Z)。READ 時のみ出力に切り替える */
    TRISD = 0xFF;
    LATD = 0x00;

    /* ICSP(RB6/RB7)はアプリ未使用。内部弱プルアップでフロート回避 */
    WPUBbits.WPUB6 = 1;
    WPUBbits.WPUB7 = 1;
}

static uint8_t bus_iorq_active(void)  { return PORTAbits.RA0 == 0; }
static uint8_t bus_addr(void)         { return PORTC; }
static uint8_t bus_rd_active(void)    { return PORTAbits.RA1 == 0; }
static uint8_t bus_wr_active(void)    { return PORTAbits.RA2 == 0; }
static uint8_t bus_read_data(void)    { return PORTD; }

static void bus_drive_data(uint8_t v)
{
    LATD = v;
    TRISD = 0x00;             /* 出力へ */
}

static void bus_release_data(void)
{
    TRISD = 0xFF;             /* 入力(Hi-Z)へ戻す */
}

static void wait_assert(void)  { LATAbits.LATA4 = 0; }  /* OD: Low ドライブ */
static void wait_release(void) { LATAbits.LATA4 = 1; }  /* OD: Hi-Z 解放    */

#else  /* !__XC8 : ホスト構文チェック用ダミー */

static void    hw_init(void)            { }
static uint8_t bus_iorq_active(void)    { return 0; }
static uint8_t bus_addr(void)           { return 0; }
static uint8_t bus_rd_active(void)      { return 0; }
static uint8_t bus_wr_active(void)      { return 0; }
static uint8_t bus_read_data(void)      { return 0; }
static void    bus_drive_data(uint8_t v){ (void)v; }
static void    bus_release_data(void)   { }
static void    wait_assert(void)        { }
static void    wait_release(void)       { }

#endif /* __XC8 */

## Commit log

2026-06-20 PC8001extSDRTC 初期設計資料を追加
    - README: 設計概要(A案=生512Bブロックデバイス・PIC18F47Q43・タイミング根拠・ロードマップ)
    - docs/protocol.md: D0H-D6H I/O 契約(SD-DOS と共有する真実)
    - hardware/: バス直結・/WAIT・SPI・I2C の方針メモ
    - firmware/: PIC18F47Q43 ファーム構成と picsd_main.c スタブ
    - LICENSE(MIT) / .gitignore
2026-06-20 docs(hardware): 回路設計仕様・結線表(フェーズA)を追加 #5
    PIC18F47Q43 を 5V 単一電源でバス直結する方針で、ブロック図・ピンアサイン表
    (PDIP-40)・ネット単位の結線表・BOM を確定。
    - 基本方針: PIC@5V でバス側レベル変換を不要化。3.3V は microSD モジュールの
    オンボード変換に委譲。RTC(DS3231)は 5V 直結。内部64MHz・水晶不要。
    - ピンアサイン: A0-A7=PORTB / D0-D7=PORTD / 制御=PORTA(/WAIT=RA4 OD) /
    SPI=RC0-2+RC5 / I2C=RC3/RC4(将来)
    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
2026-06-20 docs: ブロック図を Mermaid 化(README / hardware/design.md)
    ASCIIアートをやめ、GitHub で描画される Mermaid flowchart に置き換えて視認性を上げる。
2026-06-20 test: /WAIT 検証用の最小プログラム一対を追加 #1
    PC-8001拡張バスが /WAIT を尊重するかを SD/RTC 抜きで確かめる。
    - test/WAITTEST.asm: PC-8001側。テストポート(既定D0H)を IN/OUT し
    "RD=xx NG=nnn WR=yy" を表示(RST18H)。NG=0かつRD=55,WR=A5で合格。
    tools80でアセンブル確認済み(LOAD→G9000→BASIC復帰)。
    - firmware/waittest/waittest.c: PIC側スタブ。/WAITを下げて意図的に遅延し
    last(=55H)を返す/取り込む。実機ピンはdesign.md準拠で要実装。
    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
2026-06-20 build: ビルド用 Makefile を追加
    - make / make waittest: PC-8001側 WAITTEST.asm を tools80 でアセンブルし build/ へ
    - make fw-check: firmware の C スタブをホストコンパイラで構文チェック
    - TOOLS80 は既定 ../SD-DOS/tools/tools80.jar(同階層前提、上書き可)
    - README / test/README に make 手順を反映
2026-06-20 build: tools80 を tools/ 参照にして SD-DOS 非依存に
    ExtSD 単体でビルドできるよう、Makefile の既定 TOOLS80 を tools/tools80.jar に変更。
    jar 本体は再配布しないため非コミット(.gitignore、入手方法は tools/README.md)。
    SD-DOS と同じ流儀。
    - tools/README.md: tools80.jar の入手方法
    - .gitignore: /tools/*(!README.md)、test/*.cmt を追加
    - Makefile: TOOLS80 ?= tools/tools80.jar
    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
2026-06-20 docs(hardware): ピンアサインをデータシート(DS40002147E)で確定
    PIC18F47Q43 PDIP-40 のピン番号を Figure 2-3 / Table 3-2「40-Pin PDIP」と照合し一致を確認。
    SPI(SCK1/SDO1/SDI1)はPPS再配置可でRC0-RC2、I2CはI2C専用レベルpinのRC3/RC4(Note4)を採用。
    MCLR推奨回路(10kΩ+100〜470Ω直列+0.1µF)とICSP共有(RB6/RB7=A6/A7)をBOM/注記に反映。
    要照合→照合済みに更新。残課題は実機(/WAITタイミング・バスバッファ・ICSP分離)。
2026-06-20 chore: 外部資料用 external/ を追加(git非管理)
    データシート等の第三者配布物を置くフォルダ。本体は再配布しないため非コミット
    (.gitignore、入手方法は external/README.md)。tools/ と同じ流儀。
2026-06-21 design: ピンアサイン見直し(A0-A7=PORTC, SPI/I2C=PORTB, RB6/7=ICSP専用)
    ICSP(RB6/RB7)と拡張アドレスの衝突を構造的に排除するため、A0-A7をPORTCへ移し
    SPI/I2CをPORTBへ移設。RB6/RB7はアプリ未使用のICSP専用とし、挿したままでも
    抜いても書込競合なし。トレードはI2C専用レベルpin(RC3/RC4のみ)をアドレスに
    使う点で、I2Cは標準STレベル動作(将来RTCで実機確認)。SD_CSプルアップ・RB6/7
    フロート対策も注記。
2026-06-21 docs: ICSP弱プルアップは内部WPU/外付け不可を明記、/WAITは母板プルアップ前提に修正
    回路レビューでの誤解(ICSPCLK/DATに外付けプルアップを付けてしまう)を防ぐため、
    RB6/RB7のフロート回避は内部弱プルアップ(WPUB)で行い外付けはNGと明記。
    /WAITはPC-8001母板側でプルアップ済みのためボード側不要(BOM数0・§6更新)。
2026-06-21 feat: KiCad回路図を追加(PIC18F47Q43 / PC-8001拡張バス / SD / RTC / ICSP) #6
    フェーズA(#5)のピンアサイン・結線表どおりに回路図を入力。ネットリスト突合で
    PIC全40ピンがdesign.mdと一致、ERC0件を確認。MCLR/ICSPはR1直列分離でPGC/PGD
    クリーン、/WAITはPC-8001母板プルアップ前提。.gitignoreにKiCadのローカル設定/
    バックアップ/履歴を追加し、本体(pro/sch/pcb)とカスタムシンボルのみ追跡。
    [PC8001extSDRTC.kicad_pcb, PC8001extSDRTC.kicad_sch]
2026-06-24 feat: PCBレイアウト完成・製造用ガーバー一式を追加 #7
    回路図(#6)をもとに2層基板(100x75mm)を配線。両面GNDベタ、電源0.6mm/信号0.2mm、
    パスコンを各VDDピン至近(4mm前後)に配置。DRC 0違反・未配線0。
    製造データ(Gerber X2/mm/4.6 + Excellonドリル + zip)を hardware/KiCad/PCB/ に同梱。
    ガーバーは現行.kicad_pcbと幾何一致を確認済み。
    .gitignoreにFreerouting中間(dsn/ses/rules)と空ライブラリを追加。
    [PC8001extSDRTC-B_Cu.gbl, PC8001extSDRTC-B_Mask.gbs, PC8001extSDRTC-B_Silkscreen.gbo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]
2026-06-28 feat: /WAIT検証ファーム(waittest)を実装しXC8ビルド対応 #1
    - firmware/waittest/waittest.c: スタブから実装へ。
    - 内部64MHz HFINTOSC・config一式(WDT無効/LVP=ON 等)
    - ポート初期化: /IORQ・/RD・/WR・/RESET=RA0-3、/WAIT=RA4(ODCONでOD)、
    A0-A7=PORTC、D0-D7=PORTD(READ時のみ出力)
    - ポーリング処理: /IORQ→自ポート(D0H)宛のみ /WAIT を下げて整流。
    READ=遅延→last出力→/RD解放まで保持、WRITE=整流→取り込み。
    他ポート宛は /WAIT を触らない。
    - PIC固有部は #ifdef __XC8 でガードし host の構文チェックも通す。
    - firmware/waittest/Makefile: XC8でビルド、SNAP(ipecm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
    [waittest.c]
